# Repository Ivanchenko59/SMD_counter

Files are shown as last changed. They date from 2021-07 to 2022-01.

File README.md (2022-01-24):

# SMD counter

## About project
The device is designed to count the number of radio components in the SMD tape. The counting is based on an optical principle using an optocoupler.
The project was developed as a training project for working with STM32F103 microcontroller peripherals. The device uses the basic peripherals such as: GPIO, interrupts,    timers, I2C, ADC, etc. I also used the state machine pattern. The firmware is written with CMSIS. The circuitry of the device and the PCB were also developed. The case was modeled and 3D printed.

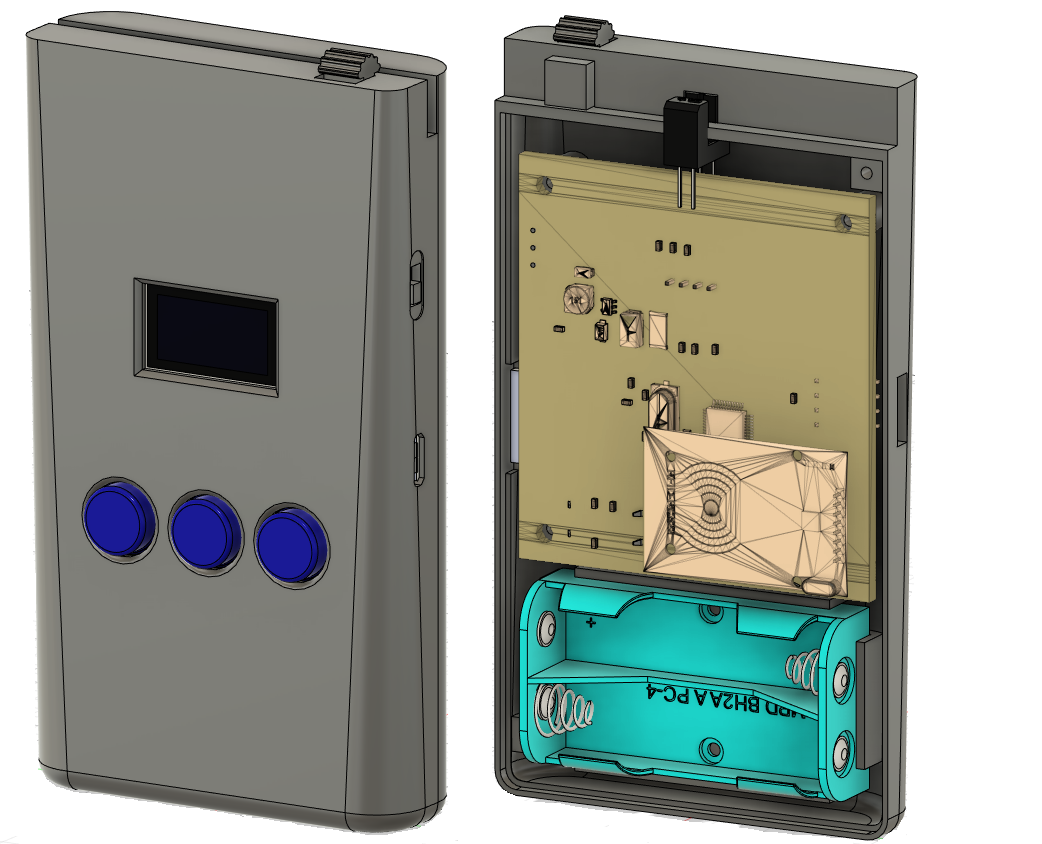
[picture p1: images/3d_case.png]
  

## Demo Video

Brief demonstration of the device menu
Watch the video (https://youtu.be/vhZqCzfXYpA)

Detailed video with a demonstration of work
Watch the video (https://youtu.be/8hMTs-ckCMA)

## Hardware
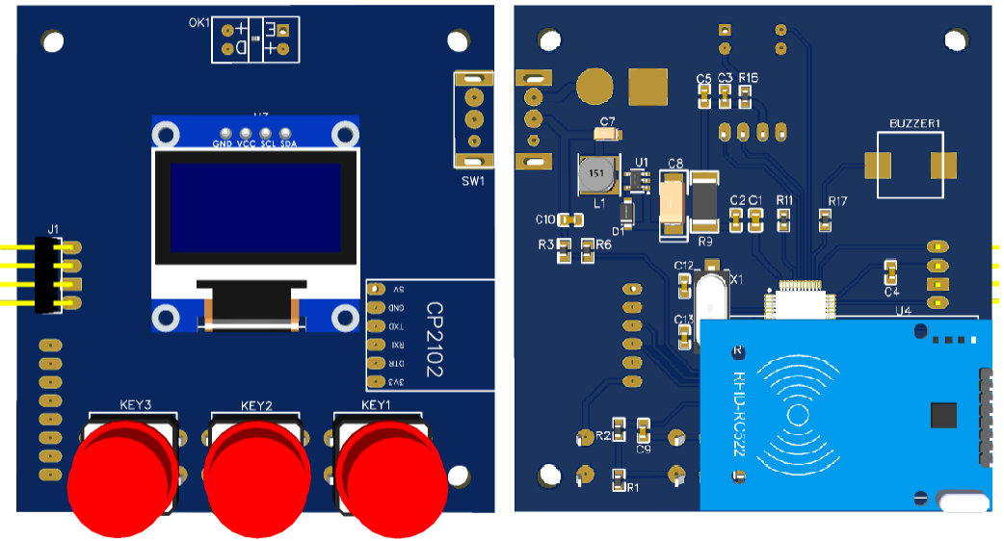
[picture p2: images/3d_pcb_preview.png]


To display information, used 0.96-inch OLED display with an I2C interface. Menu control is carried out using three buttons. The board also has a CP2102 UART converter for communicating with a computer, as well as an RFID module for reading tags, for organizing a warehouse and tracking the presence of components (not implemented at the moment).

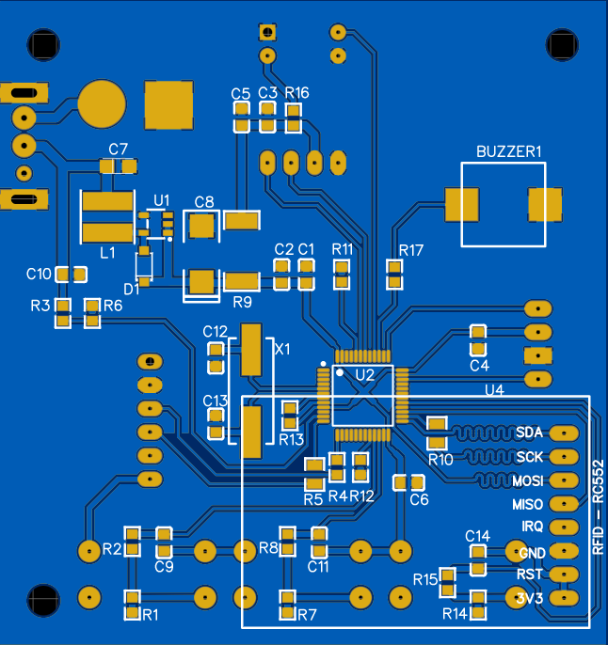
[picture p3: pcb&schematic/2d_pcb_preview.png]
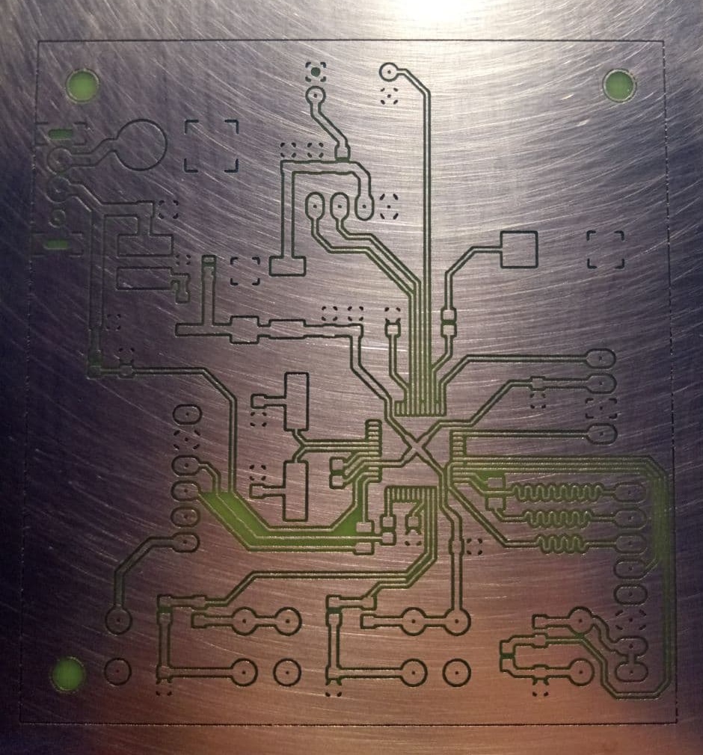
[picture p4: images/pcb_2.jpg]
 

The device is powered by two 1.5V AA batteries. To increase the voltage to 3.3V used a step-up DC-DC converter based on the NCP1402 chip.

### Detailed circuit schematic

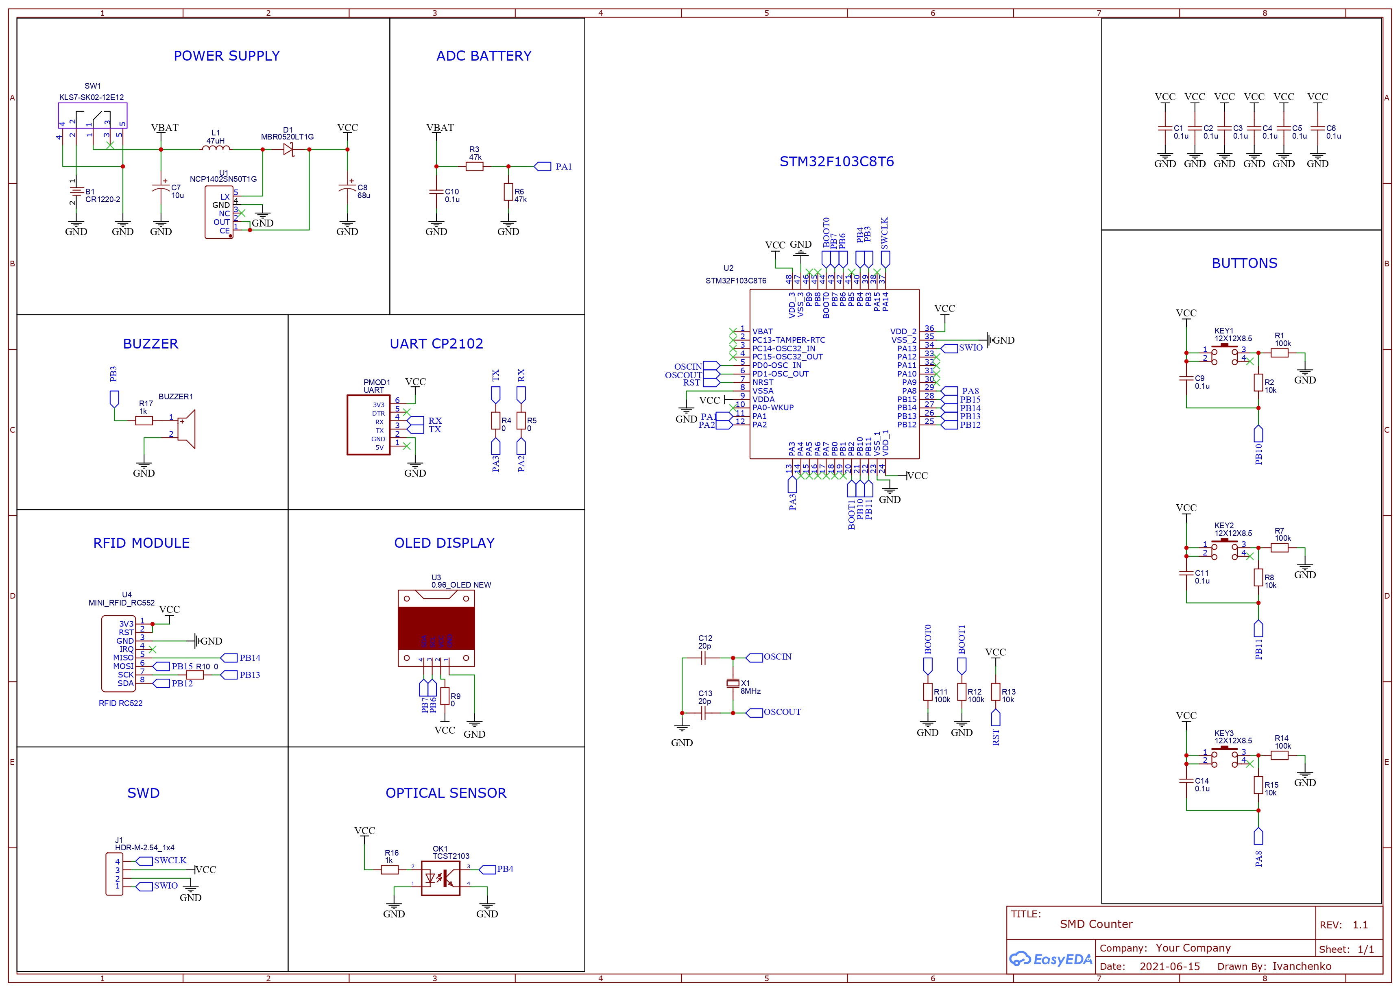
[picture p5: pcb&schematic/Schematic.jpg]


## Menu organization

After turning on the device, the animation of the running SMD tape will be played on the screen.

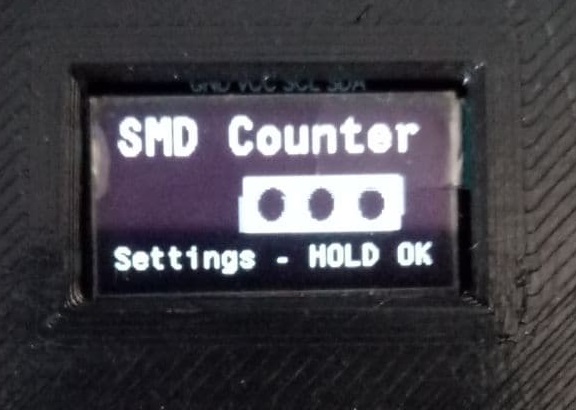
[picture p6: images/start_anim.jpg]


After that, the user enters the main menu, from which you can enter the settings menu by holding the OK button, or start reading with a single press. On the screen there is a battery level, as well as a step size (for example, if two leads on the tape correspond to one component, the step is set to 2).

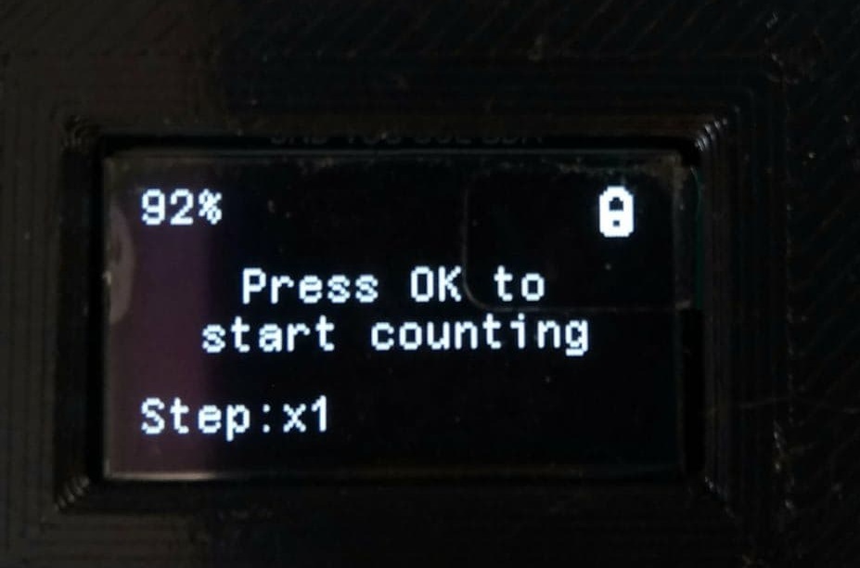
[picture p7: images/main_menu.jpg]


In order to count the number of SMD elements in the tape, press the OK button, and pass the tape through the guide slot in the housing. On the screen you will see the current number of counted items in the tape.

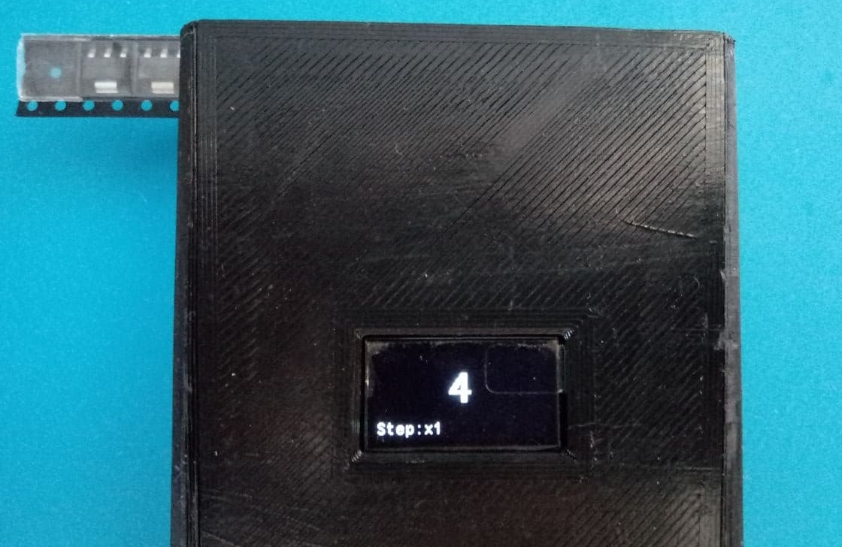
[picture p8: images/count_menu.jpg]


After the end of counting, and long holding the OK button, you will be taken to the save menu, where you can save the current value, change it, or continue counting.

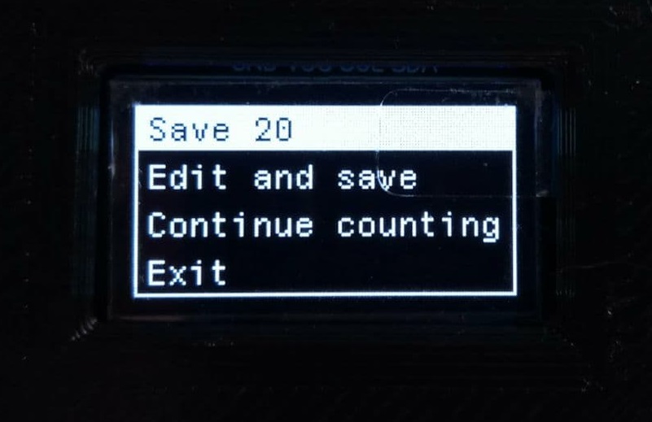
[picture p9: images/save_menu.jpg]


Edit menu for changing the current value looks like this:

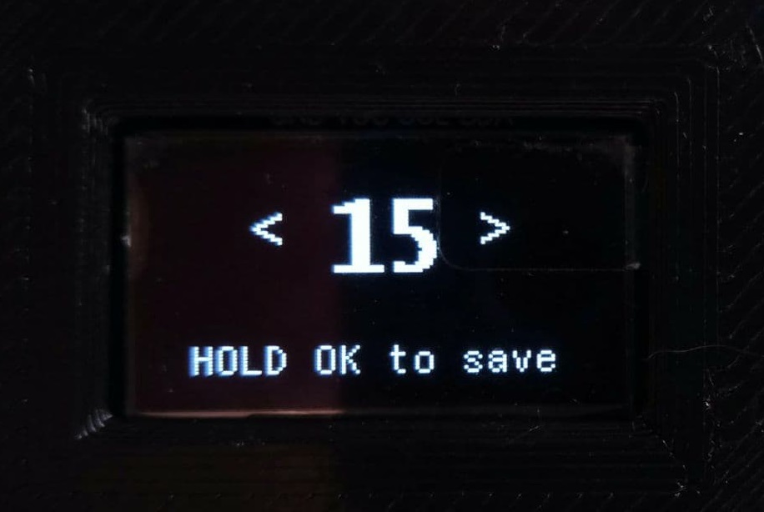
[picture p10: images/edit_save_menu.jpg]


After saving, the user returns to the main menu, and the calculated value is transferred to the database, which is accessed through the settings.
The settings menu looks like this:

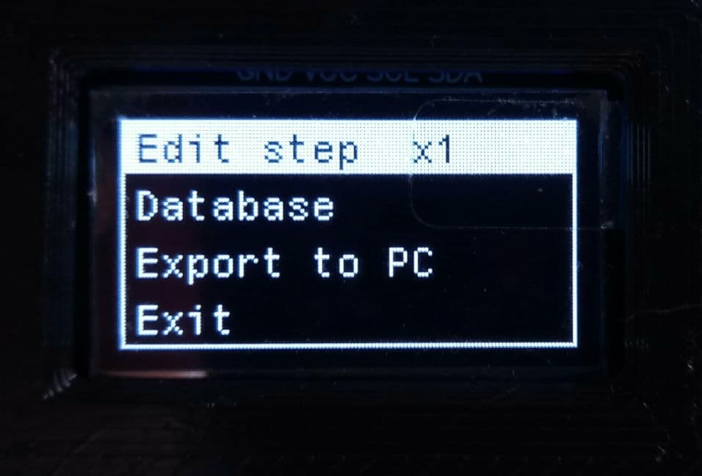
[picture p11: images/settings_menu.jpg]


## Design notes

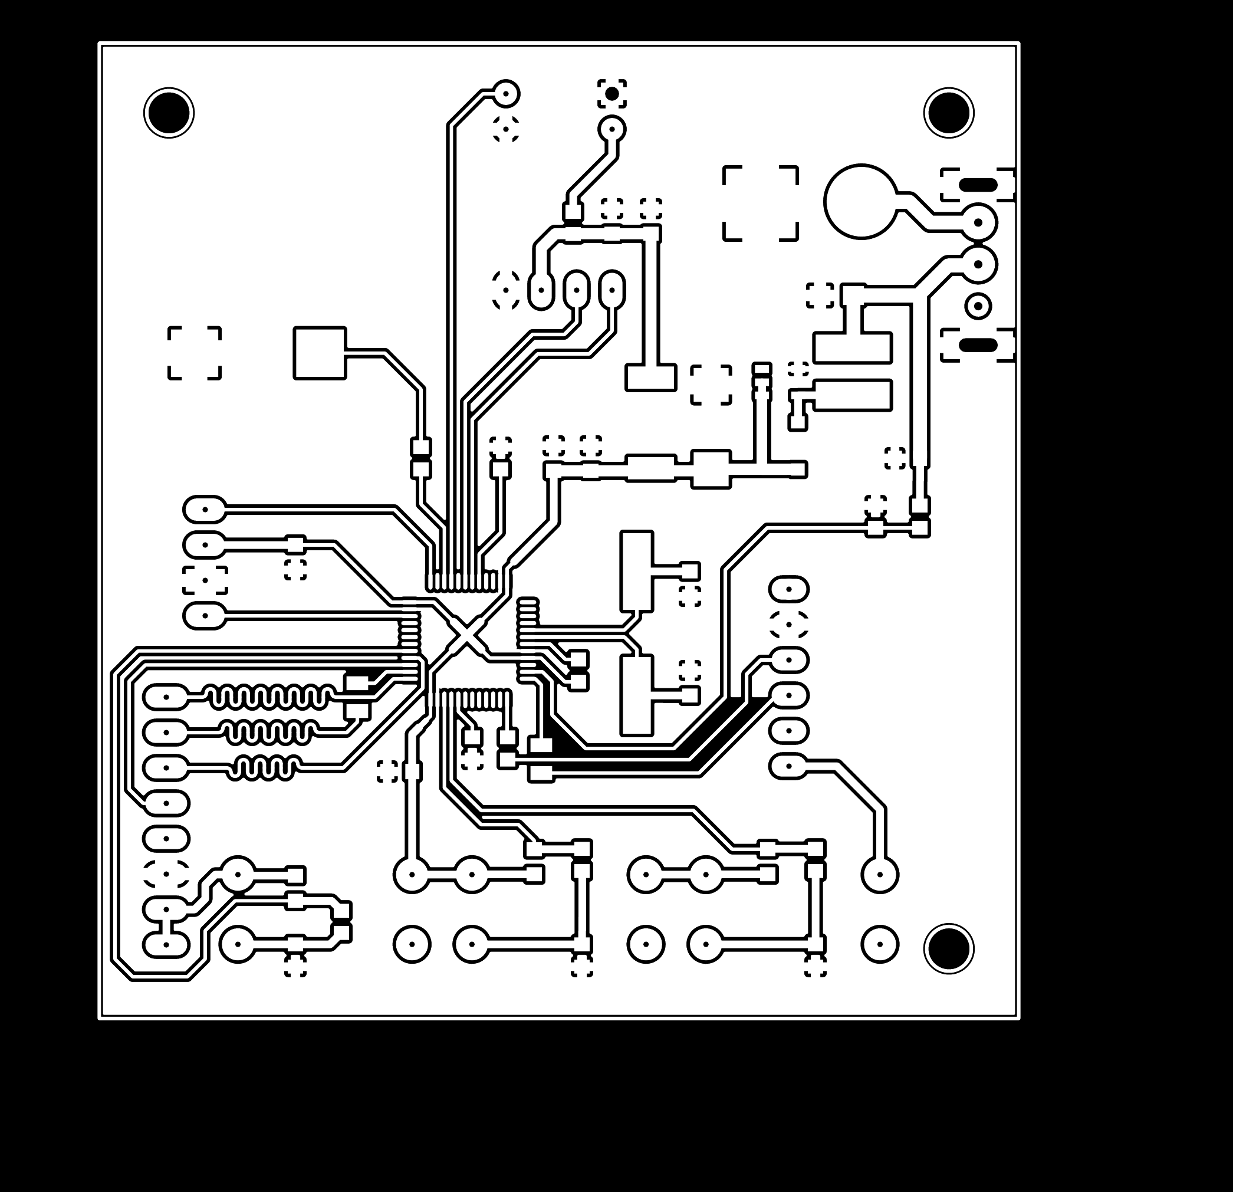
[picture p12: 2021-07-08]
pcb&schematic/pcb_for_diy.png

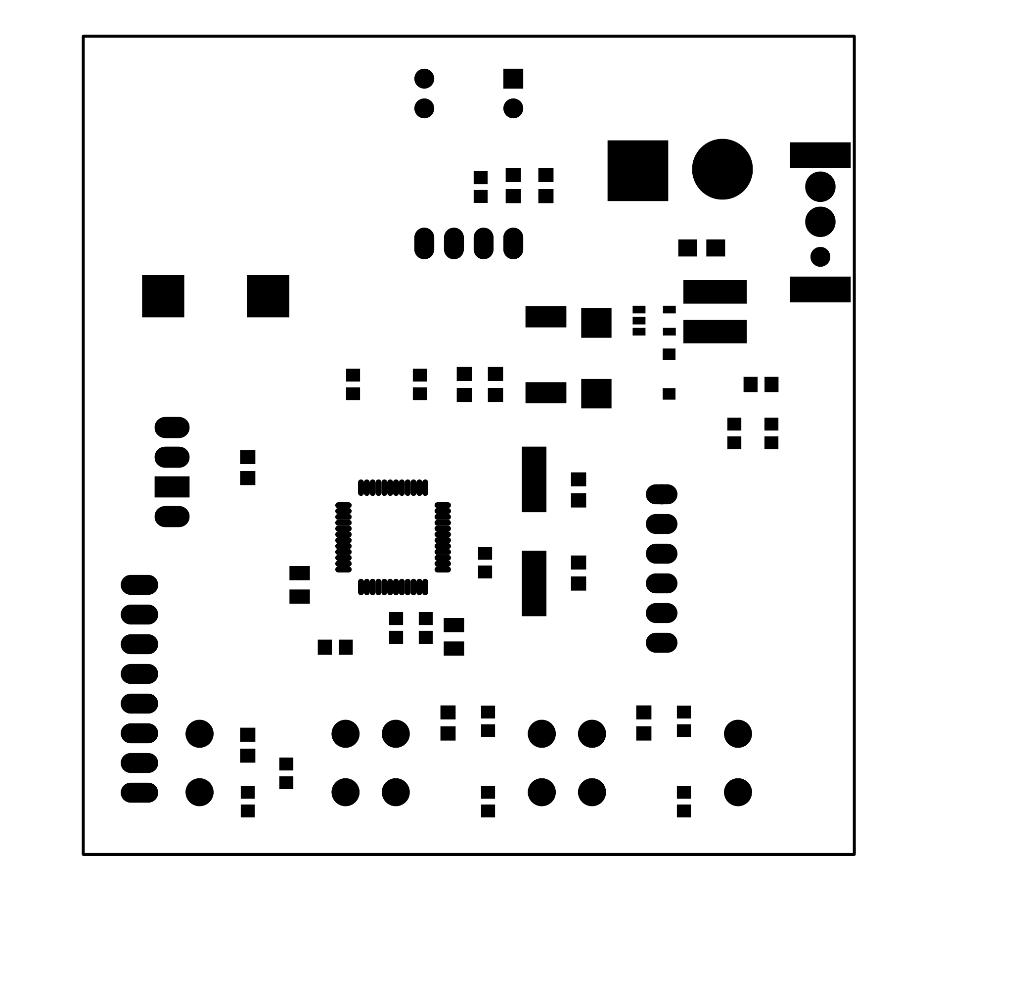
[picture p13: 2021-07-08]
pcb&schematic/mask_for_diy.png

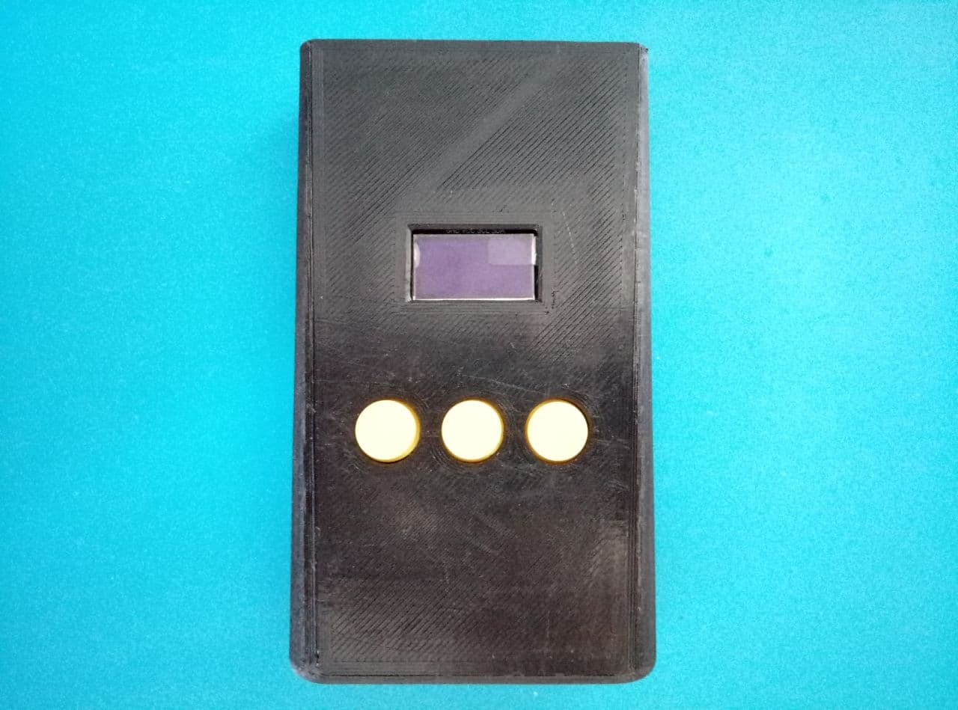
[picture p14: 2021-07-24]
images/case1.jpg

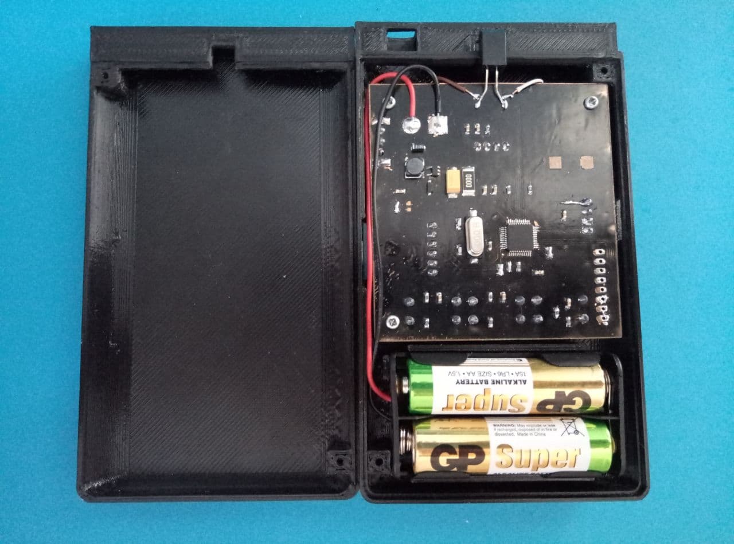
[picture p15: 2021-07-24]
images/case3.jpg

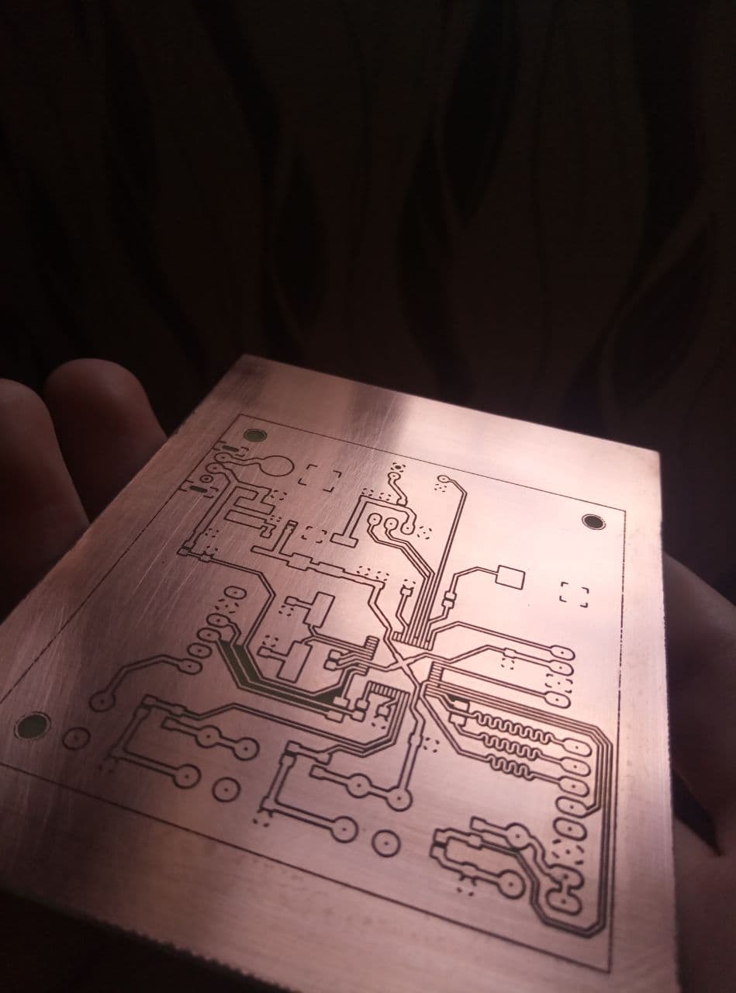
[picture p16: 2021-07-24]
images/pcb.jpg

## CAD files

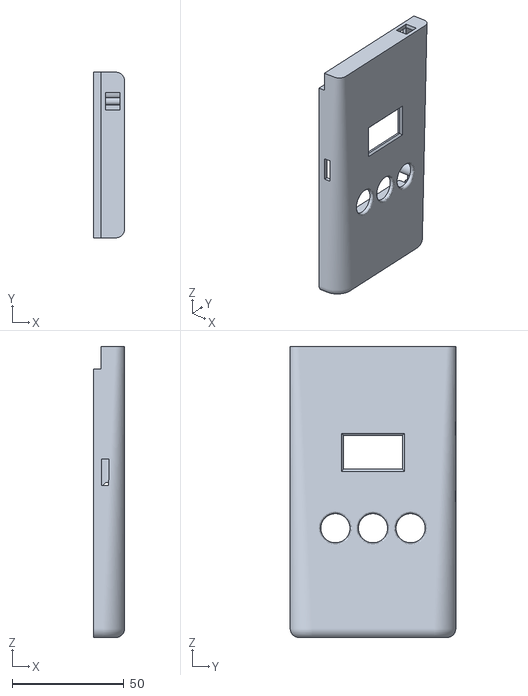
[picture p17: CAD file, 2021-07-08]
3d case/FrontPlate.stl
14.0 x 74.0 x 130.0

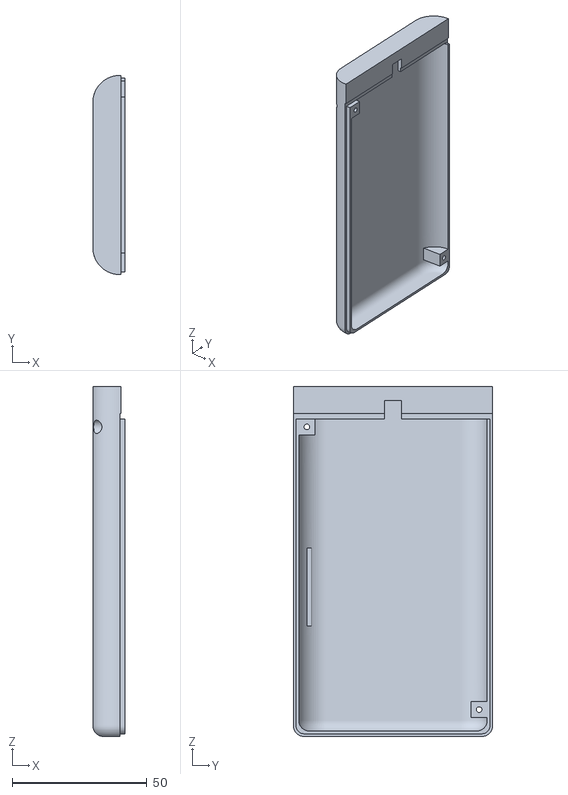
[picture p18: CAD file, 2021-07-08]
3d case/BackPlate.stl
12.0 x 74.0 x 130.0

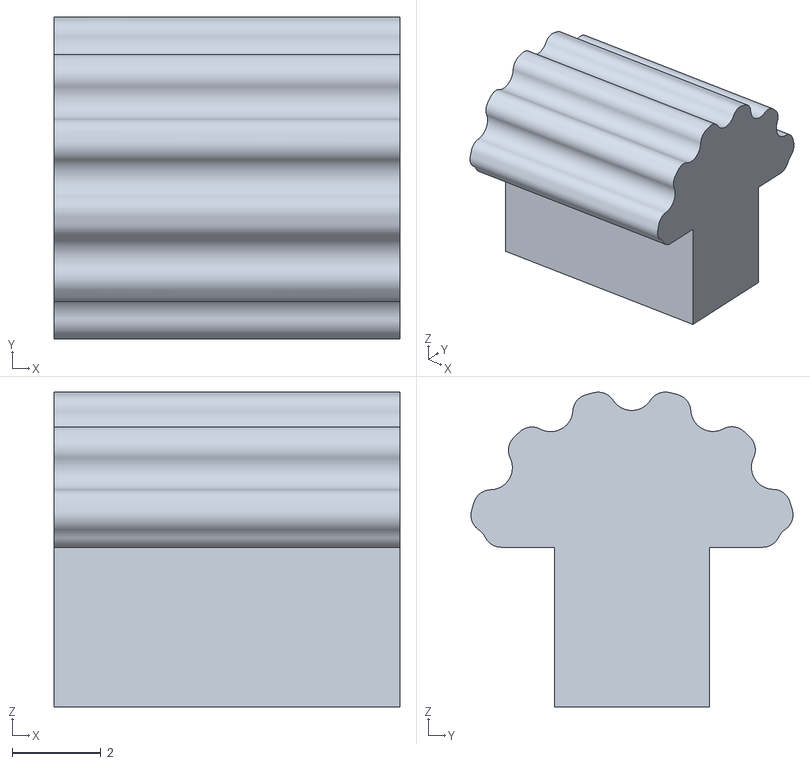
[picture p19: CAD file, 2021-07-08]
3d case/Slider.stl
7.80 x 7.26 x 7.10

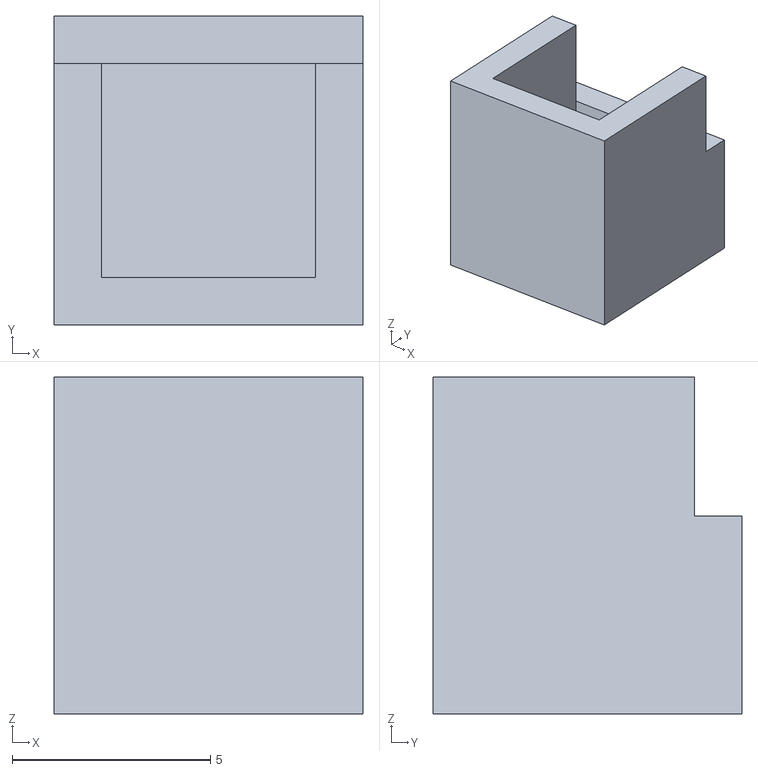
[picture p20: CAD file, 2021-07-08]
3d case/Stopper.stl
7.80 x 7.80 x 8.50

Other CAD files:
3d case/SMD-counter.f3z

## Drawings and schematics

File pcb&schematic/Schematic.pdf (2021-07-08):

## ADC BATTERY

## STM32F103C8T6

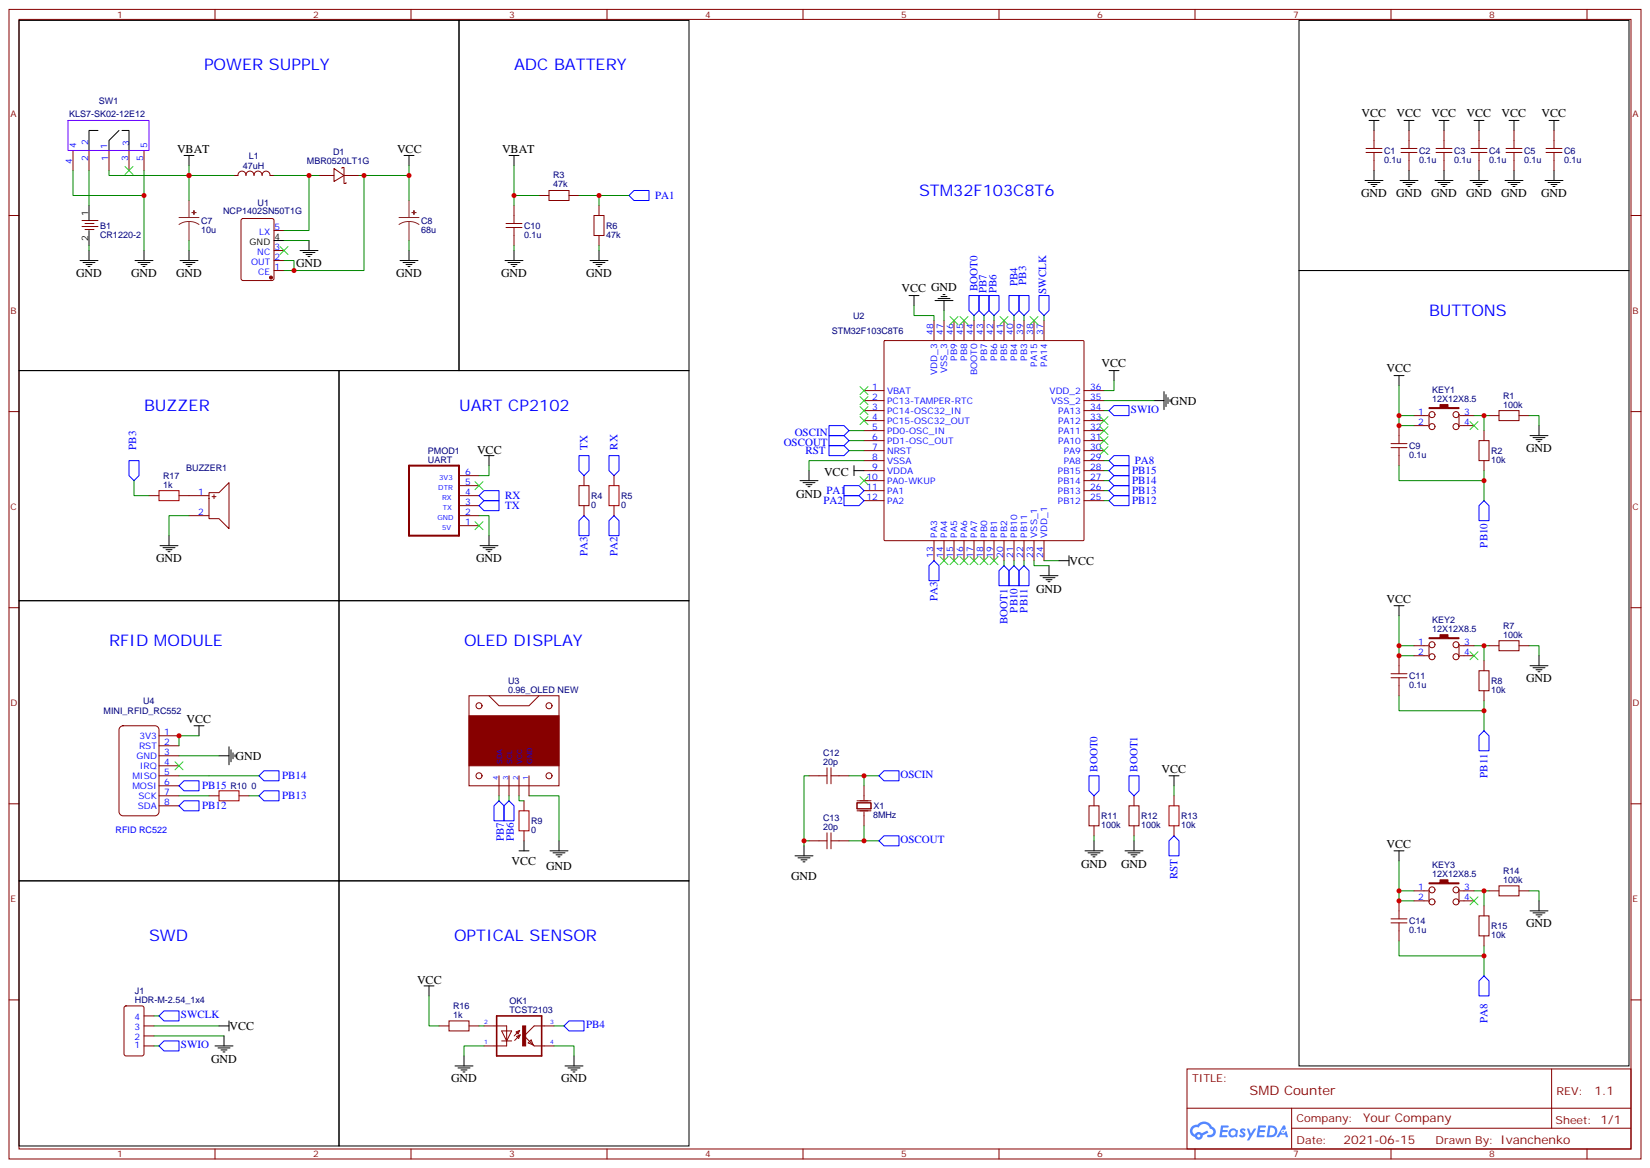
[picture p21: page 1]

VCC VCC

GND GND

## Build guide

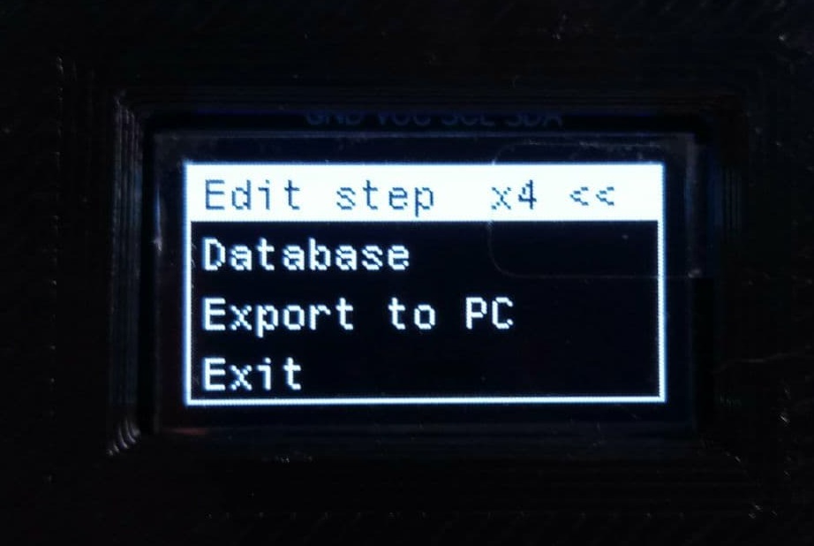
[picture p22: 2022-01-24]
images/edit_step.jpg

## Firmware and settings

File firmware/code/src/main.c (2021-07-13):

#include "main.h"

volatile uint32_t front_counter = 0, front_counter_continue = 0, smd_counter, smd_counter_continue;
uint8_t skip_first_front = 0;
uint16_t battery_voltage;
int main() {
	
	mcu_init();
	welcome_menu();
	
	while(1) {
		if (state == STATE_COUNT_MENU) {
			EXTI->IMR |= EXTI_IMR_MR4;
		}
		else {
			EXTI->IMR &= ~EXTI_IMR_MR4;
		}
		
		SSD1306_Fill(SSD1306_COLOR_BLACK);
		
		transition_table[state][event]();
		button_check();
		
		SSD1306_UpdateScreen();
	}
}

void mcu_init() {
	SysTick_Config(SystemCoreClock/1000);	
	SSD1306_Init();
	button_init();
	TCST_init();
	ADC1_init();
	TMR4_init();
}	

void SysTick_Handler() {
	sys_tick++;
}

void EXTI4_IRQHandler(void) {
	//clear the bit at the beginning, because at the end the bit "does not have time to be cleared"
	EXTI->PR |= EXTI_PR_PR4;
	if (skip_first_front > 0) {
		front_counter++;
		front_counter_continue++;
		smd_counter = front_counter / step_size;
	}
	skip_first_front = 1;
}

void TIM4_IRQHandler(void) {
    battery_voltage = expRunningAverage(get_battery_voltage());
    TIM4->SR &= ~TIM_SR_UIF; // сбрасываем прерывание
}

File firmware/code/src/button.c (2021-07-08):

#include "button.h"

#define BUTTON_SHORT_PRESS_DELAY 150
#define BUTTON_LONG_PRESS_DELAY 1000
#define STEP_SIZE_MAX 8

uint32_t ok_time = 0;
uint32_t left_time = 0;
uint32_t right_time = 0;

typedef struct {   
	__IO uint8_t ok_state : 1;
	__IO uint8_t ok_short_state : 1;
	__IO uint8_t ok_long_state : 1;
	__IO uint8_t left_press  : 1;
	__IO uint8_t right_press : 1;
} bit_fied_TypeDef;

bit_fied_TypeDef btn = {0, 0, 0, 1, 1};

void button_init() {
	//clocking PORT A, PORT B and AFIO for enable AFIO multiplexer 
	RCC->APB2ENR |= RCC_APB2ENR_IOPAEN 
				 | RCC_APB2ENR_IOPBEN 
				 | RCC_APB2ENR_AFIOEN;
	
	//http://easyelectronics.ru/arm-uchebnyj-kurs-vneshnie-preryvaniya.html
	AFIO->EXTICR[2] |= AFIO_EXTICR3_EXTI8_PA 
					| AFIO_EXTICR3_EXTI10_PB 
					| AFIO_EXTICR3_EXTI11_PB;
	
	//Init OK button
	GPIOB->CRH &= ~GPIO_CRH_MODE10;
	GPIOB->CRH |= GPIO_CRH_CNF10_1;
	GPIOB->CRH &= ~GPIO_CRH_CNF10_0;
		
	//Init RIGHT button
	GPIOB->CRH &= ~GPIO_CRH_MODE11;
	GPIOB->CRH |= GPIO_CRH_CNF11_1;
	GPIOB->CRH &= ~GPIO_CRH_CNF11_0;
	
	//Init LEFT button
	GPIOA->CRH &= ~GPIO_CRH_MODE8;
	GPIOA->CRH |= GPIO_CRH_CNF8_1;
	GPIOA->CRH &= ~GPIO_CRH_CNF8_0;
}

void button_check() {
	
	btn.ok_state = ((GPIOB->IDR & GPIO_IDR_IDR10) == GPIO_IDR_IDR10);
	
	if (btn.ok_state && !btn.ok_short_state && ((sys_tick - ok_time) > BUTTON_SHORT_PRESS_DELAY)) {
		btn.ok_short_state = 1;
		btn.ok_long_state = 0;
		ok_time = sys_tick;
	}
	else if (btn.ok_state && !btn.ok_long_state && (sys_tick - ok_time) > BUTTON_LONG_PRESS_DELAY) {
		btn.ok_long_state = 1;
		event = EVENT_BTN_LONG;
	}
	else if (!btn.ok_state && btn.ok_short_state && (sys_tick - ok_time) > BUTTON_SHORT_PRESS_DELAY) {
		btn.ok_short_state = 0;
		ok_time = sys_tick;
		if(!btn.ok_long_state) {
			event = EVENT_BTN_SHORT;
		}
	}
	
	//if we are not in the line menu, do not check the left and right buttons
	if (state == STATE_SAVE_MENU || state == STATE_SETTING_MENU || state == STATE_DATABASE_MENU) {

		//LEFT button
		if ((GPIOA->IDR & GPIO_IDR_IDR8) == GPIO_IDR_IDR8 && btn.left_press) {
			btn.left_press = 0;
			if (edit_step_flag){
				step_size = constrain(step_size - 1, 1, STEP_SIZE_MAX);
			}
			else if (edit_counter_flag) {
				if (smd_counter > 0) {
					smd_counter--;
				}
			}
			else if (edit_db_flag) {
				if (database[pointer] > 0) {
					database[pointer]--;
				}
			}
			else {
				pointer--;
			}
			left_time = sys_tick;
		}
		if (!btn.left_press && (sys_tick - left_time) > BUTTON_SHORT_PRESS_DELAY) {
			btn.left_press = 1;
		}
		
		//RIGHT button
		if ((GPIOB->IDR & GPIO_IDR_IDR11) == GPIO_IDR_IDR11 && btn.right_press) {
			btn.right_press = 0;
			if (edit_step_flag){
				step_size = constrain(step_size + 1, 1, STEP_SIZE_MAX);
			}
			else if (edit_counter_flag) {
				smd_counter++;
			}
			else if (edit_db_flag) {
				database[pointer]++;
			}
			else {
				pointer++;
			}
			right_time = sys_tick;
		}
		if (!btn.right_press && (sys_tick - right_time) > BUTTON_SHORT_PRESS_DELAY) {
			btn.right_press = 1;
		}
	}
	
	else {
		pointer = 0;
	}
}

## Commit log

2021-06-29 treatment buttons on the function with the support the debouncing button
2021-07-01 Little refactoring code, add edit menu, init i2c to fast mode
2021-07-08 Add 3d case
    [BackPlate.stl, FrontPlate.stl, Slider.stl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]
2021-07-08 add pcb and schematic
2021-07-09 add case in Fusion360 file
    [SMD-counter.f3z]
2021-07-09 add true counting, fix position display text
    [main.c, utils.c]
2021-07-10 add skip first front signal
    [main.c]
2021-07-13 Adding battery voltage status
2021-07-13 added filter for ADC
